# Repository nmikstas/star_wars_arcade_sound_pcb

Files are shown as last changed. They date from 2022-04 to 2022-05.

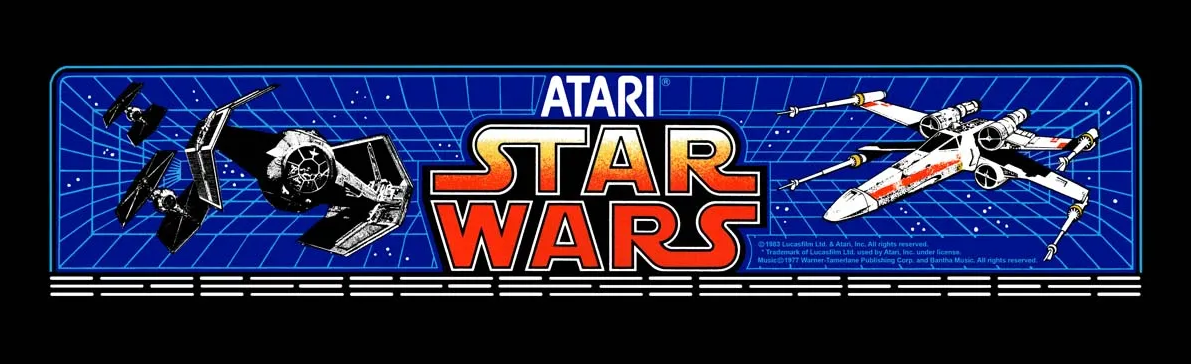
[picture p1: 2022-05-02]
images/star_wars_marquee.png

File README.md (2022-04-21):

# star_wars_arcade_sound_pcb
Reproduction of the Star Wars arcade sound PCB. The PCB is complete but not yet verified.

# Folder Structure
* BOM - Bill of materials for the sound PCB
* Gerbers - The gerber files for the sound PCB
* images - The images used for the sound PCB
* pcb - The Kicad design files for the sound PCB

# PCB Specifications
* Layers: 2
* Dimensions: 293mm X 227mm
* Different PCB Design: 1
* PCB Thickness: 1.6mm
* Surface Finish: HASL
* Castellated Holes: No
* Copper Weight: 1oz.

# The Complete Star Wars Arcade PCB Repository Collection
* Main PCB: https://github.com/nmikstas/star_wars_arcade_main_pcb
* AVG PCB: https://github.com/nmikstas/star_wars_arcade_avg_pcb
* Sound PCB: https://github.com/nmikstas/star_wars_arcade_sound_pcb
* EMI PCB: https://github.com/nmikstas/star_wars_arcade_emi_pcb
* Interconnect PCB: 
* AVG Chip: https://github.com/nmikstas/atari-avg-replacements
* Varistor Replacement: https://github.com/nmikstas/atari_voltage_dependent_resistor
* Mathbox ROM Replacement:
* State Machine Adapter PCB:

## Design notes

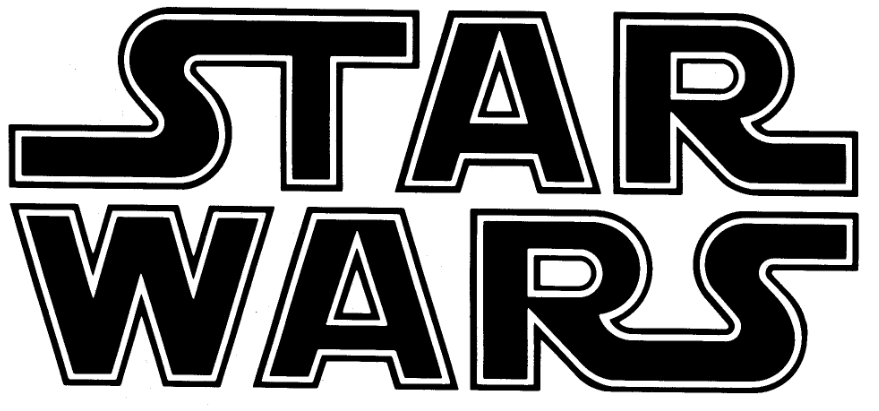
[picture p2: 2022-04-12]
images/star_wars.png

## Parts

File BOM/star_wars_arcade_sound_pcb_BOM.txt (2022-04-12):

Part_ID                                                 QTY     DESC            Part_Num

C1,  C2,  C3,  C4,  C5,  C6,  C7,  C8,  C9,  C10,       41      0.1uf           Digikey 399-4454-1-ND
C11, C12, C16, C17, C18, C19, C20, C22, C23, C24,
C25, C26, C27, C28, C30, C37, C38, C40, C41, C42,
C43, C45, C54, C55, C59, C60, C61, C31, C32, C34,
C36
C46, C48, C49, C50, C56, C57, C58                       7       0.0027uf        Digikey 478-11573-1-ND
C13, C14, C15, C47, C53		                            5       100uf 50V       Digikey 1572-1309-ND
C29, C33, C35, C39                                      4       1000pf          Digikey 1216PHCT-ND
C44                                                     1       0.01uf          Digikey 399-4452-1-ND
C51                                                     1       0.47uf          Digikey 1572-1461-ND‎
C52                                                     1       10uf            Digikey 1572-1294-ND

DS1                                                     1       BLUE LED        Digikey VAOL-5701SBY4-ND

P2                                                      1       7 pin con       Digikey A19878-ND‎

Q1, Q2                                                  2       2N3906          Digikey 2N3906TAFSCT-ND
Q3, Q4                                                  2       2N3904          Digikey 2N3904TAFSCT-ND

R1,  R4,  R7,  R12, R15, R20, R22, R24, R26             9       1K              Digikey 1.0KQBK-ND
R2,  R3,  R5,  R6,  R10, R13, R17, R37                  8       10K             Digikey 10KQBK-ND
R30, R39, R40, R42, R46, R47                            6       12K             Digikey 12KQBK-ND
R21, R23, R50, R54, R55                                 5       47K             Digikey 47KQBK-ND
R48, R49, R52, R53                                      4       22K             Digikey 22KQBK-ND
R35, R51, R56                                           3       2.2K            Digikey 2.2KQBK-ND
R8,  R9,  R44                                           3       100             Digikey 100QBK-ND
R11, R14, R16                                           3       3.3K            Digikey 3.3KQBK-ND
R25, R27                                                2       82K             Digikey 82KQBK-ND
R33, R34                                                2       4.7K            Digikey 4.7KQBK-ND
R31, R32                                                2       560K            Digikey 560KQBK-ND
R19, R28                                                2       100K            Digikey 100KQBK-ND
R18                                                     1       1.8K            Digikey 1.8KQBK-ND
R29                                                     1       15K             Digikey 15KQBK-ND
R36                                                     1       15              Digikey 15QBK-ND
R38                                                     1       470             Digikey 470QBK-ND
R41                                                     1       68K             Digikey 68KQBK-ND
R43                                                     1       1.5K            Digikey 1.5KQBK-ND
R45                                                     1       470K            Digikey 470KQBK-ND

TP1,  TP2, TP3, TP4, TP5, TP6, TP7, TP8, TP9, TP10      12      Test Point      Digikey WM6456-ND
TP11, TP12

D-2, D-3, D-4, D-5                                      4       POKEY           Ebay
B-2, C-3, C-4                                           3       TL084           Digikey 296-1782-5-ND‎
H-1, J/K-1                                              2       2764            Jameco 2303119
F-3, F-5                                                2       LS161           Digikey 296-1646-5-ND
J-2, J-3                                                2       LS139           Digikey 296-1640-5-ND
J-5, K-5                                                2       LS374           Jameco 47634
C/D-1                                                   1       TMS-5220        Ebay
F/H-1                                                   1       6116-2K-RAM     Jameco 242675
F/H-5                                                   1       LS125           Jameco 46501
E-1                                                     1       PIA             Ebay
F-2                                                     1       CD4069/74C04    Jameco 13231
A-3                                                     1       NE556           Jameco 904114
B-3                                                     1       R5106           Ebay
H-2                                                     1       LS04            Jameco 46316
H-3                                                     1       LS00            Jameco 46252
H-5                                                     1       LS74            Jameco 48004
K-3                                                     1       6809E           Ebay

IC Sockets
-------------------
8  pin     1
14 pin     9
16-pin     4
20-pin     2
24-pin     1
28-pin     3
40-pin     6

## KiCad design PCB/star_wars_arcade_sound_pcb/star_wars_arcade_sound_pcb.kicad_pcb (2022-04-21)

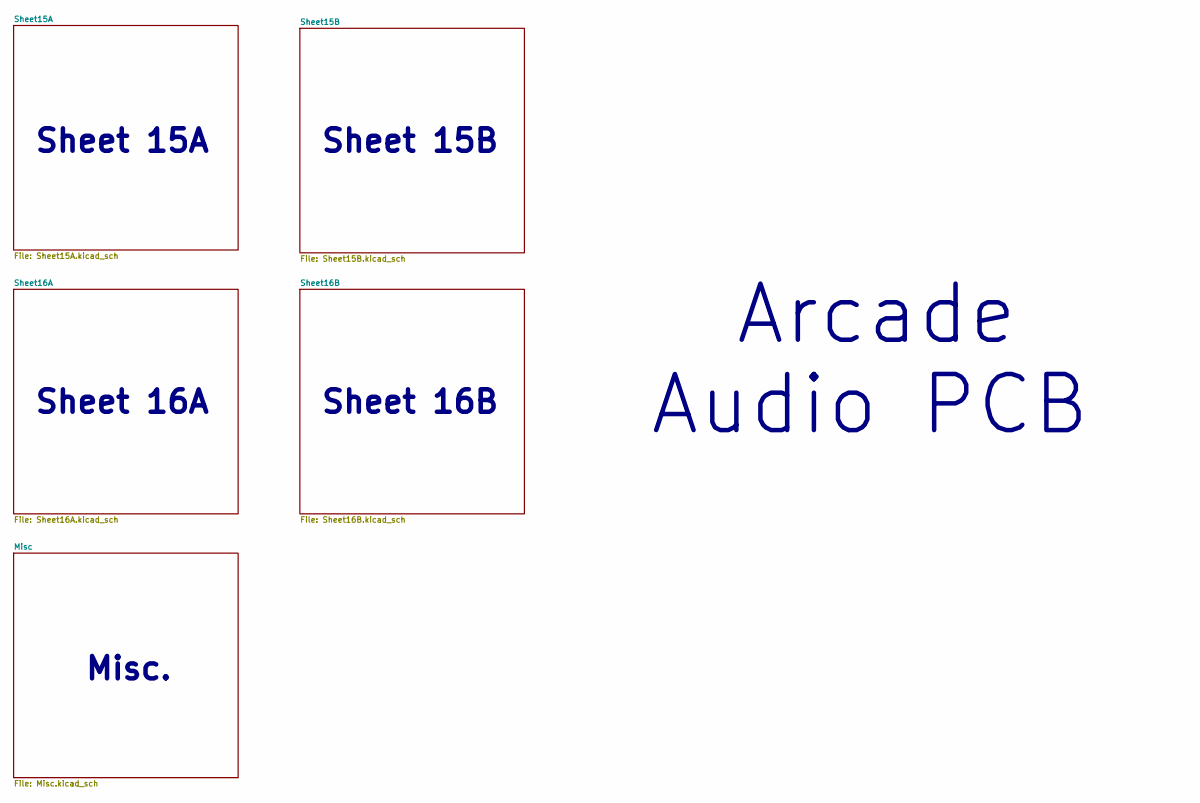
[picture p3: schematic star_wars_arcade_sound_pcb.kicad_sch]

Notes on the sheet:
Sheet 15A
Sheet 16A
Sheet 15B
Arcade Audio PCB
Sheet 16B
Misc.

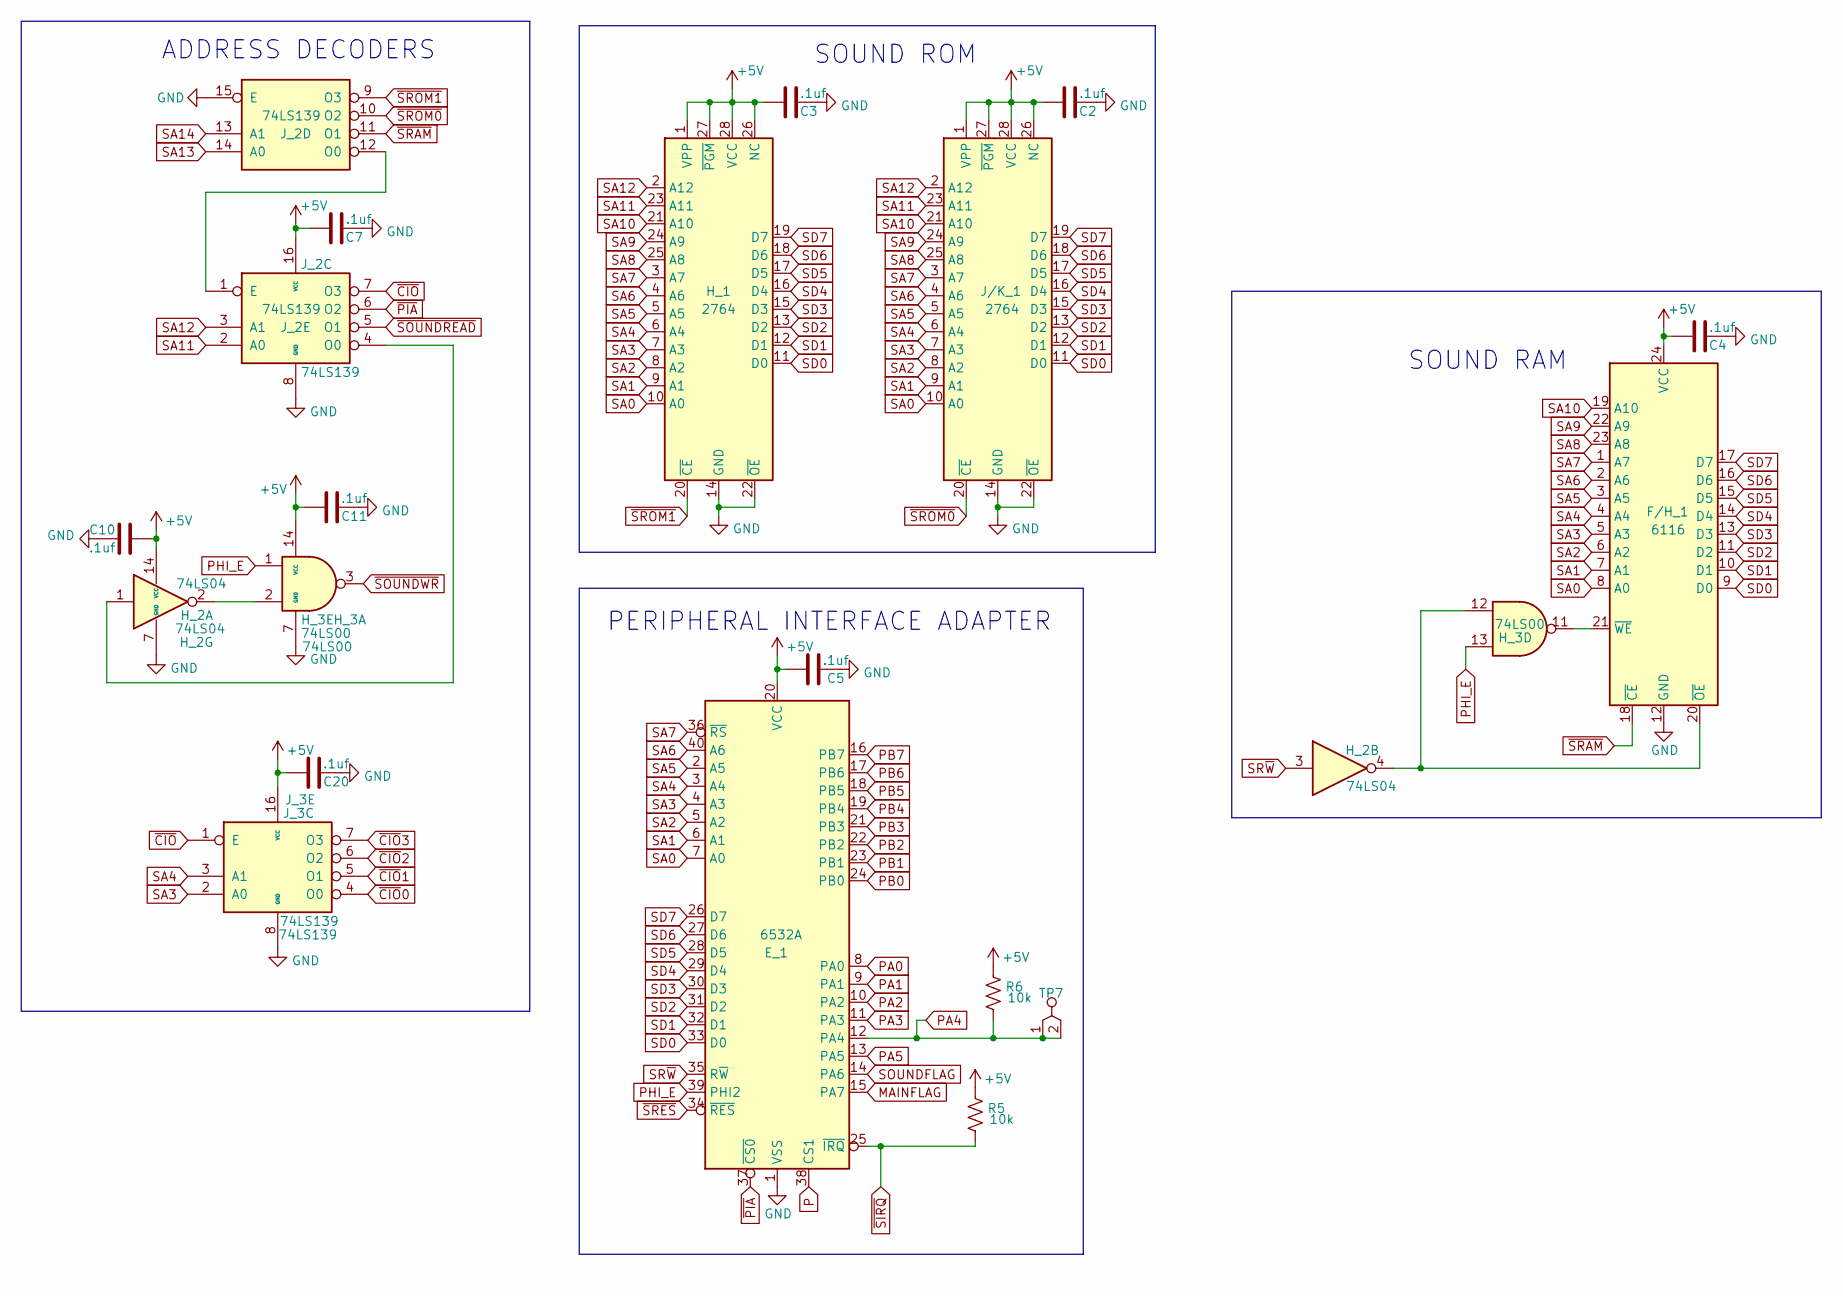
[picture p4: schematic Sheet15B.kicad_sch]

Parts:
C2, C3, C4, C5, C7, C10, C11, C20: .1uf; GenericComp
E_1: 6532A; DDIP40
F/H_1: 6116; DDIP24
H_1: 2764; DIP28
H_2: 74LS04; DIP14
H_3: 74LS00; DIP14
J/K_1: 2764; DIP28
J_2, J_3: 74LS139; DIP16
R5, R6: 10k; GenericComp
TP7: tp_2_pin; TEST_POINT

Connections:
+5V: C2.1, C3.1, C4.1, C5.1, C7.1, C10.1, C11.1, C20.1, E_1.20 (VCC), F/H_1.24 (VCC), H_1.1 (VPP), H_1.26 (NC), H_1.27 (~PGM), H_1.28 (VCC), H_2.14 (VCC), H_3.14 (VCC), J/K_1.1 (VPP), J/K_1.26 (NC), J/K_1.27 (~PGM), J/K_1.28 (VCC), J_2.16 (VCC), J_3.16 (VCC), R5.1, R6.1; also elsewhere on the board
GND: C2.2, C3.2, C4.2, C5.2, C7.2, C10.2, C11.2, C20.2, E_1.1 (VSS), F/H_1.12 (GND), H_1.14 (GND), H_1.22 (~OE), H_2.7 (GND), H_3.7 (GND), J/K_1.14 (GND), J/K_1.22 (~OE), J_2.8 (GND), J_2.15 (E), J_3.8 (GND); also elsewhere on the board
MAINFLAG: E_1.15 (PA7); also elsewhere on the board
unnamed: F/H_1.20 (~OE), H_2.4, H_3.12
unnamed: F/H_1.21 (~WE), H_3.11
unnamed: H_2.1, J_2.4 (O0)
unnamed: H_2.2, H_3.2
unnamed: J_2.1 (E), J_2.12 (O0)
P: E_1.38 (CS1); also elsewhere on the board
PA0: E_1.8 (PA0); also elsewhere on the board
PA1: E_1.9 (PA1); also elsewhere on the board
PA2: E_1.10 (PA2); also elsewhere on the board
PA3: E_1.11 (PA3); also elsewhere on the board
PA4: E_1.12 (PA4), R6.2, TP7.1, TP7.2
PA5: E_1.13 (PA5); also elsewhere on the board
PB0: E_1.24 (PB0); also elsewhere on the board
PB1: E_1.23 (PB1); also elsewhere on the board
PB2: E_1.22 (PB2); also elsewhere on the board
PB3: E_1.21 (PB3); also elsewhere on the board
PB4: E_1.19 (PB4); also elsewhere on the board
PB5: E_1.18 (PB5); also elsewhere on the board
PB6: E_1.17 (PB6); also elsewhere on the board
PB7: E_1.16 (PB7); also elsewhere on the board
PHI_E: E_1.39 (PHI2), H_3.1, H_3.13; also elsewhere on the board
SA0: E_1.7 (A0), F/H_1.8 (A0), H_1.10 (A0), J/K_1.10 (A0); also elsewhere on the board
SA1: E_1.6 (A1), F/H_1.7 (A1), H_1.9 (A1), J/K_1.9 (A1); also elsewhere on the board
SA2: E_1.5 (A2), F/H_1.6 (A2), H_1.8 (A2), J/K_1.8 (A2); also elsewhere on the board
SA3: E_1.4 (A3), F/H_1.5 (A3), H_1.7 (A3), J/K_1.7 (A3), J_3.2 (A0); also elsewhere on the board
SA4: E_1.3 (A4), F/H_1.4 (A4), H_1.6 (A4), J/K_1.6 (A4), J_3.3 (A1); also elsewhere on the board
SA5: E_1.2 (A5), F/H_1.3 (A5), H_1.5 (A5), J/K_1.5 (A5); also elsewhere on the board
SA6: E_1.40 (A6), F/H_1.2 (A6), H_1.4 (A6), J/K_1.4 (A6); also elsewhere on the board
SA7: E_1.36 (~RS), F/H_1.1 (A7), H_1.3 (A7), J/K_1.3 (A7); also elsewhere on the board
SA8: F/H_1.23 (A8), H_1.25 (A8), J/K_1.25 (A8); also elsewhere on the board
SA9: F/H_1.22 (A9), H_1.24 (A9), J/K_1.24 (A9); also elsewhere on the board
SA10: F/H_1.19 (A10), H_1.21 (A10), J/K_1.21 (A10); also elsewhere on the board
SA11: H_1.23 (A11), J/K_1.23 (A11), J_2.2 (A0); also elsewhere on the board
SA12: H_1.2 (A12), J/K_1.2 (A12), J_2.3 (A1); also elsewhere on the board
SA13: J_2.14 (A0); also elsewhere on the board
SA14: J_2.13 (A1); also elsewhere on the board
SD0: E_1.33 (D0), F/H_1.9 (D0), H_1.11 (D0), J/K_1.11 (D0); also elsewhere on the board
SD1: E_1.32 (D1), F/H_1.10 (D1), H_1.12 (D1), J/K_1.12 (D1); also elsewhere on the board
SD2: E_1.31 (D2), F/H_1.11 (D2), H_1.13 (D2), J/K_1.13 (D2); also elsewhere on the board
SD3: E_1.30 (D3), F/H_1.13 (D3), H_1.15 (D3), J/K_1.15 (D3); also elsewhere on the board
SD4: E_1.29 (D4), F/H_1.14 (D4), H_1.16 (D4), J/K_1.16 (D4); also elsewhere on the board
SD5: E_1.28 (D5), F/H_1.15 (D5), H_1.17 (D5), J/K_1.17 (D5); also elsewhere on the board
SD6: E_1.27 (D6), F/H_1.16 (D6), H_1.18 (D6), J/K_1.18 (D6); also elsewhere on the board
SD7: E_1.26 (D7), F/H_1.17 (D7), H_1.19 (D7), J/K_1.19 (D7); also elsewhere on the board
SOUNDFLAG: E_1.14 (PA6); also elsewhere on the board
SR~W: E_1.35 (R~W), H_2.3; also elsewhere on the board
~CIO: J_2.7 (O3), J_3.1 (E)
~CIO0: J_3.4 (O0); also elsewhere on the board
~CIO1: J_3.5 (O1); also elsewhere on the board
~CIO2: J_3.6 (O2); also elsewhere on the board
~CIO3: J_3.7 (O3); also elsewhere on the board
~PIA: E_1.37 (~CS0), J_2.6 (O2)
~SIRQ: E_1.25 (~IRQ), R5.2; also elsewhere on the board
~SOUNDREAD: J_2.5 (O1); also elsewhere on the board
~SOUNDWR: H_3.3; also elsewhere on the board
~SRAM: F/H_1.18 (~CE), J_2.11 (O1)
~SRES: E_1.34 (~RES); also elsewhere on the board
~SROM0: J/K_1.20 (~CE), J_2.10 (O2)
~SROM1: H_1.20 (~CE), J_2.9 (O3)

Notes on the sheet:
PERIPHERAL INTERFACE ADAPTER
ADDRESS DECODERS
SOUND RAM
SOUND ROM

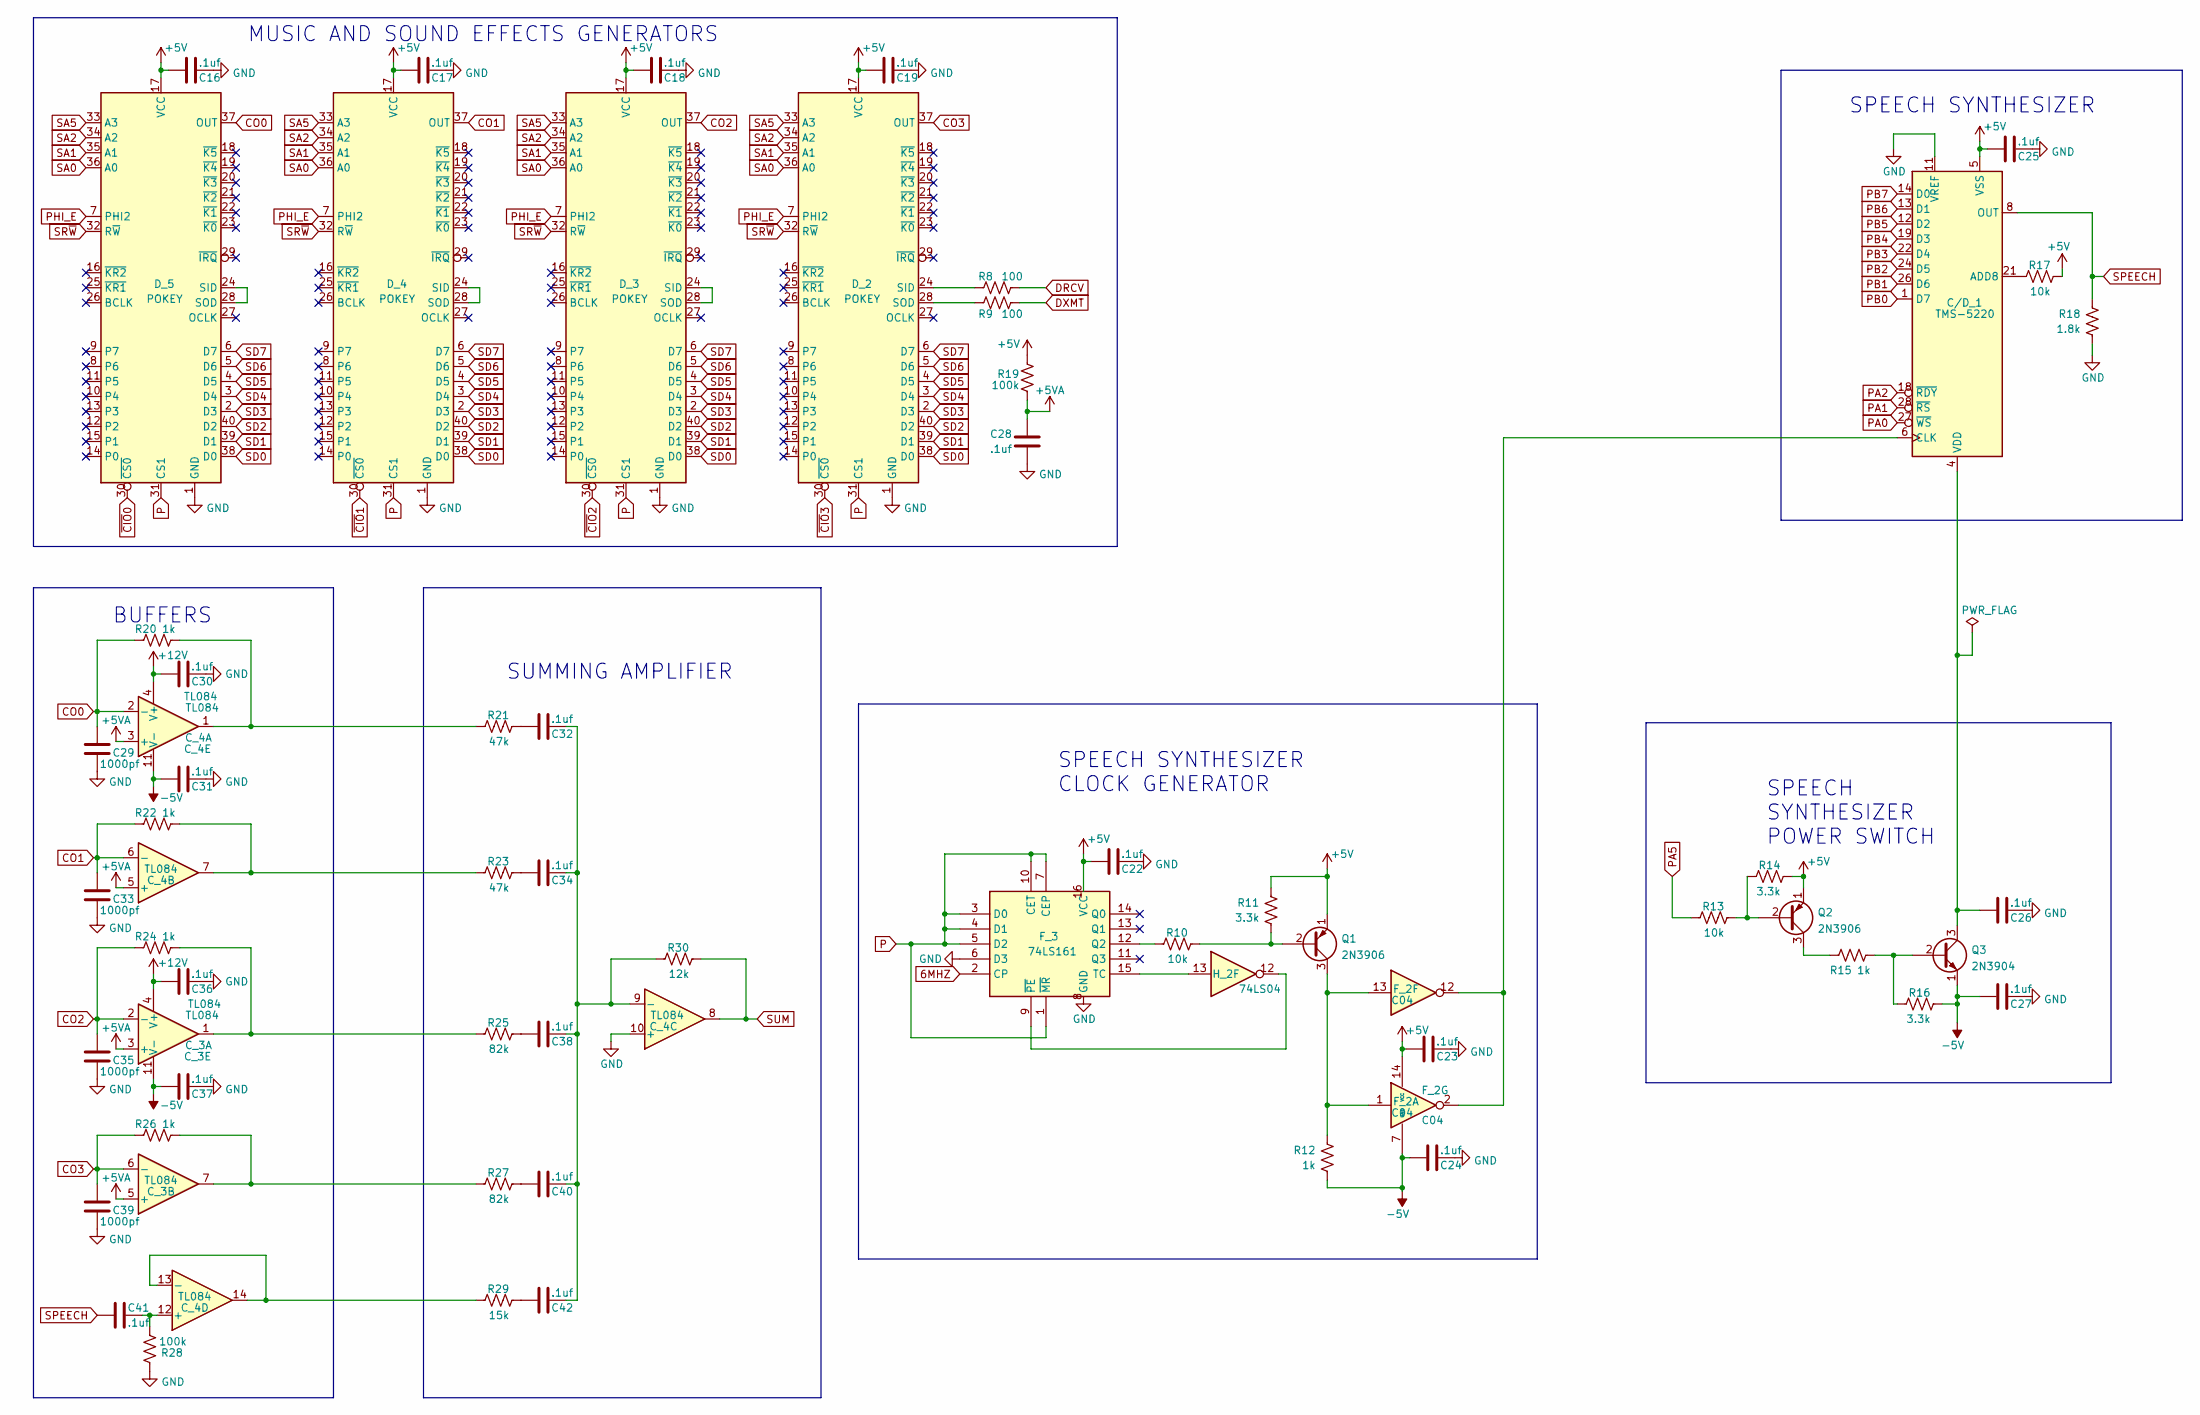
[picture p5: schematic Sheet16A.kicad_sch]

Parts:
C16, C17, C18, C19, C22, C23, C24, C25, C26, C27, C28, C30, C31, C32, C34, C36, C37, C38, C40, C41, C42: .1uf; GenericComp
C29, C33, C35, C39: 1000pf; GenericComp
C/D_1: TMS-5220; DIP28
C_3, C_4: TL084; DIP14
D_2, D_3, D_4, D_5: POKEY; DDIP40
F_2: C04; DIP14
F_3: 74LS161; DIP16
H_2: 74LS04; DIP14
Q1, Q2: 2N3906; GenericTrans
Q3: 2N3904; GenericTrans
R8, R9: 100; GenericComp
R10, R13, R17: 10k; GenericComp
R11, R14, R16: 3.3k; GenericComp
R12, R15, R20, R22, R24, R26: 1k; GenericComp
R18: 1.8k; GenericComp
R19, R28: 100k; GenericComp
R21, R23: 47k; GenericComp
R25, R27: 82k; GenericComp
R29: 15k; GenericComp
R30: 12k; GenericComp

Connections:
6MHZ: F_3.2 (CP); also elsewhere on the board
+5V: C16.1, C17.1, C18.1, C19.1, C22.1, C23.1, C25.1, C/D_1.5 (VSS), D_2.17 (VCC), D_3.17 (VCC), D_4.17 (VCC), D_5.17 (VCC), F_2.14 (VCC), F_3.16 (VCC), Q1.1 (E), Q2.1 (E), R11.2, R14.2, R17.2, R19.2; also elsewhere on the board
+5VA: C28.2, C_3.3 (+), C_3.5 (+), C_4.3 (+), C_4.5 (+), R19.1
+12V: C30.1, C36.1, C_3.4 (V+), C_4.4 (V+); also elsewhere on the board
-5V: C24.1, C27.1, C31.1, C37.1, C_3.11 (V-), C_4.11 (V-), F_2.7 (GND), Q3.1 (E), R12.1, R16.2; also elsewhere on the board
CO0: C29.2, C_4.2 (-), D_5.37 (OUT), R20.1
CO1: C33.2, C_4.6 (-), D_4.37 (OUT), R22.1
CO2: C35.2, C_3.2 (-), D_3.37 (OUT), R24.1
CO3: C39.2, C_3.6 (-), D_2.37 (OUT), R26.1
DRCV: R8.2; also elsewhere on the board
DXMT: R9.2; also elsewhere on the board
GND: C16.2, C17.2, C18.2, C19.2, C22.2, C23.2, C24.2, C25.2, C26.2, C27.2, C28.1, C29.1, C30.2, C31.2, C33.1, C35.1, C36.2, C37.2, C39.1, C/D_1.11 (VREF), C_4.10 (+), D_2.1 (GND), D_3.1 (GND), D_4.1 (GND), D_5.1 (GND), F_3.6 (D3), F_3.8 (GND), R18.1, R28.1; also elsewhere on the board
unnamed: C32.1, R21.2
unnamed: C32.2, C34.2, C38.2, C40.2, C42.2, C_4.9 (-), R30.1
unnamed: C34.1, R23.2
unnamed: C38.1, R25.2
unnamed: C40.1, R27.2
unnamed: C41.1, C_4.12 (+), R28.2
unnamed: C42.1, R29.2
unnamed: C26.1, C/D_1.4 (VDD), Q3.3 (C)
unnamed: C/D_1.6 (CLK), F_2.2, F_2.12
unnamed: C/D_1.21 (ADD8), R17.1
unnamed: C_3.1, R24.2, R25.1
unnamed: C_3.7, R26.2, R27.1
unnamed: C_4.1, R20.2, R21.1
unnamed: C_4.7, R22.2, R23.1
unnamed: C_4.13 (-), C_4.14, R29.1
unnamed: D_2.24 (SID), R8.1
unnamed: D_2.28 (SOD), R9.1
unnamed: D_3.24 (SID), D_3.28 (SOD)
unnamed: D_4.24 (SID), D_4.28 (SOD)
unnamed: D_5.24 (SID), D_5.28 (SOD)
unnamed: F_2.1, F_2.13, Q1.3 (C), R12.2
unnamed: F_3.9 (~PE), H_2.12
unnamed: F_3.12 (Q2), R10.1
unnamed: F_3.15 (TC), H_2.13
unnamed: Q1.2 (B), R10.2, R11.1
unnamed: Q2.2 (B), R13.2, R14.1
unnamed: Q2.3 (C), R15.1
unnamed: Q3.2 (B), R15.2, R16.1
P: D_2.31 (CS1), D_3.31 (CS1), D_4.31 (CS1), D_5.31 (CS1), F_3.1 (~MR), F_3.3 (D0), F_3.4 (D1), F_3.5 (D2), F_3.7 (CEP), F_3.10 (CET); also elsewhere on the board
PA0: C/D_1.27 (~WS); also elsewhere on the board
PA1: C/D_1.28 (~RS); also elsewhere on the board
PA2: C/D_1.18 (~RDY); also elsewhere on the board
PA5: R13.1; also elsewhere on the board
PB0: C/D_1.1 (D7); also elsewhere on the board
PB1: C/D_1.26 (D6); also elsewhere on the board
PB2: C/D_1.24 (D5); also elsewhere on the board
PB3: C/D_1.22 (D4); also elsewhere on the board
PB4: C/D_1.19 (D3); also elsewhere on the board
PB5: C/D_1.12 (D2); also elsewhere on the board
PB6: C/D_1.13 (D1); also elsewhere on the board
PB7: C/D_1.14 (D0); also elsewhere on the board
PHI_E: D_2.7 (PHI2), D_3.7 (PHI2), D_4.7 (PHI2), D_5.7 (PHI2); also elsewhere on the board
SA0: D_2.36 (A0), D_3.36 (A0), D_4.36 (A0), D_5.36 (A0); also elsewhere on the board
SA1: D_2.35 (A1), D_3.35 (A1), D_4.35 (A1), D_5.35 (A1); also elsewhere on the board
SA2: D_2.34 (A2), D_3.34 (A2), D_4.34 (A2), D_5.34 (A2); also elsewhere on the board
SA5: D_2.33 (A3), D_3.33 (A3), D_4.33 (A3), D_5.33 (A3); also elsewhere on the board
SD0: D_2.38 (D0), D_3.38 (D0), D_4.38 (D0), D_5.38 (D0); also elsewhere on the board
SD1: D_2.39 (D1), D_3.39 (D1), D_4.39 (D1), D_5.39 (D1); also elsewhere on the board
SD2: D_2.40 (D2), D_3.40 (D2), D_4.40 (D2), D_5.40 (D2); also elsewhere on the board
SD3: D_2.2 (D3), D_3.2 (D3), D_4.2 (D3), D_5.2 (D3); also elsewhere on the board
SD4: D_2.3 (D4), D_3.3 (D4), D_4.3 (D4), D_5.3 (D4); also elsewhere on the board
SD5: D_2.4 (D5), D_3.4 (D5), D_4.4 (D5), D_5.4 (D5); also elsewhere on the board
SD6: D_2.5 (D6), D_3.5 (D6), D_4.5 (D6), D_5.5 (D6); also elsewhere on the board
SD7: D_2.6 (D7), D_3.6 (D7), D_4.6 (D7), D_5.6 (D7); also elsewhere on the board
SPEECH: C41.2, C/D_1.8 (OUT), R18.2
SR~W: D_2.32 (R~W), D_3.32 (R~W), D_4.32 (R~W), D_5.32 (R~W); also elsewhere on the board
SUM: C_4.8, R30.2; also elsewhere on the board
~CIO0: D_5.30 (~CS0); also elsewhere on the board
~CIO1: D_4.30 (~CS0); also elsewhere on the board
~CIO2: D_3.30 (~CS0); also elsewhere on the board
~CIO3: D_2.30 (~CS0); also elsewhere on the board

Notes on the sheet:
SPEECH SYNTHESIZER CLOCK GENERATOR
BUFFERS
SPEECH SYNTHESIZER POWER SWITCH
MUSIC AND SOUND EFFECTS GENERATORS
SPEECH SYNTHESIZER
SUMMING AMPLIFIER

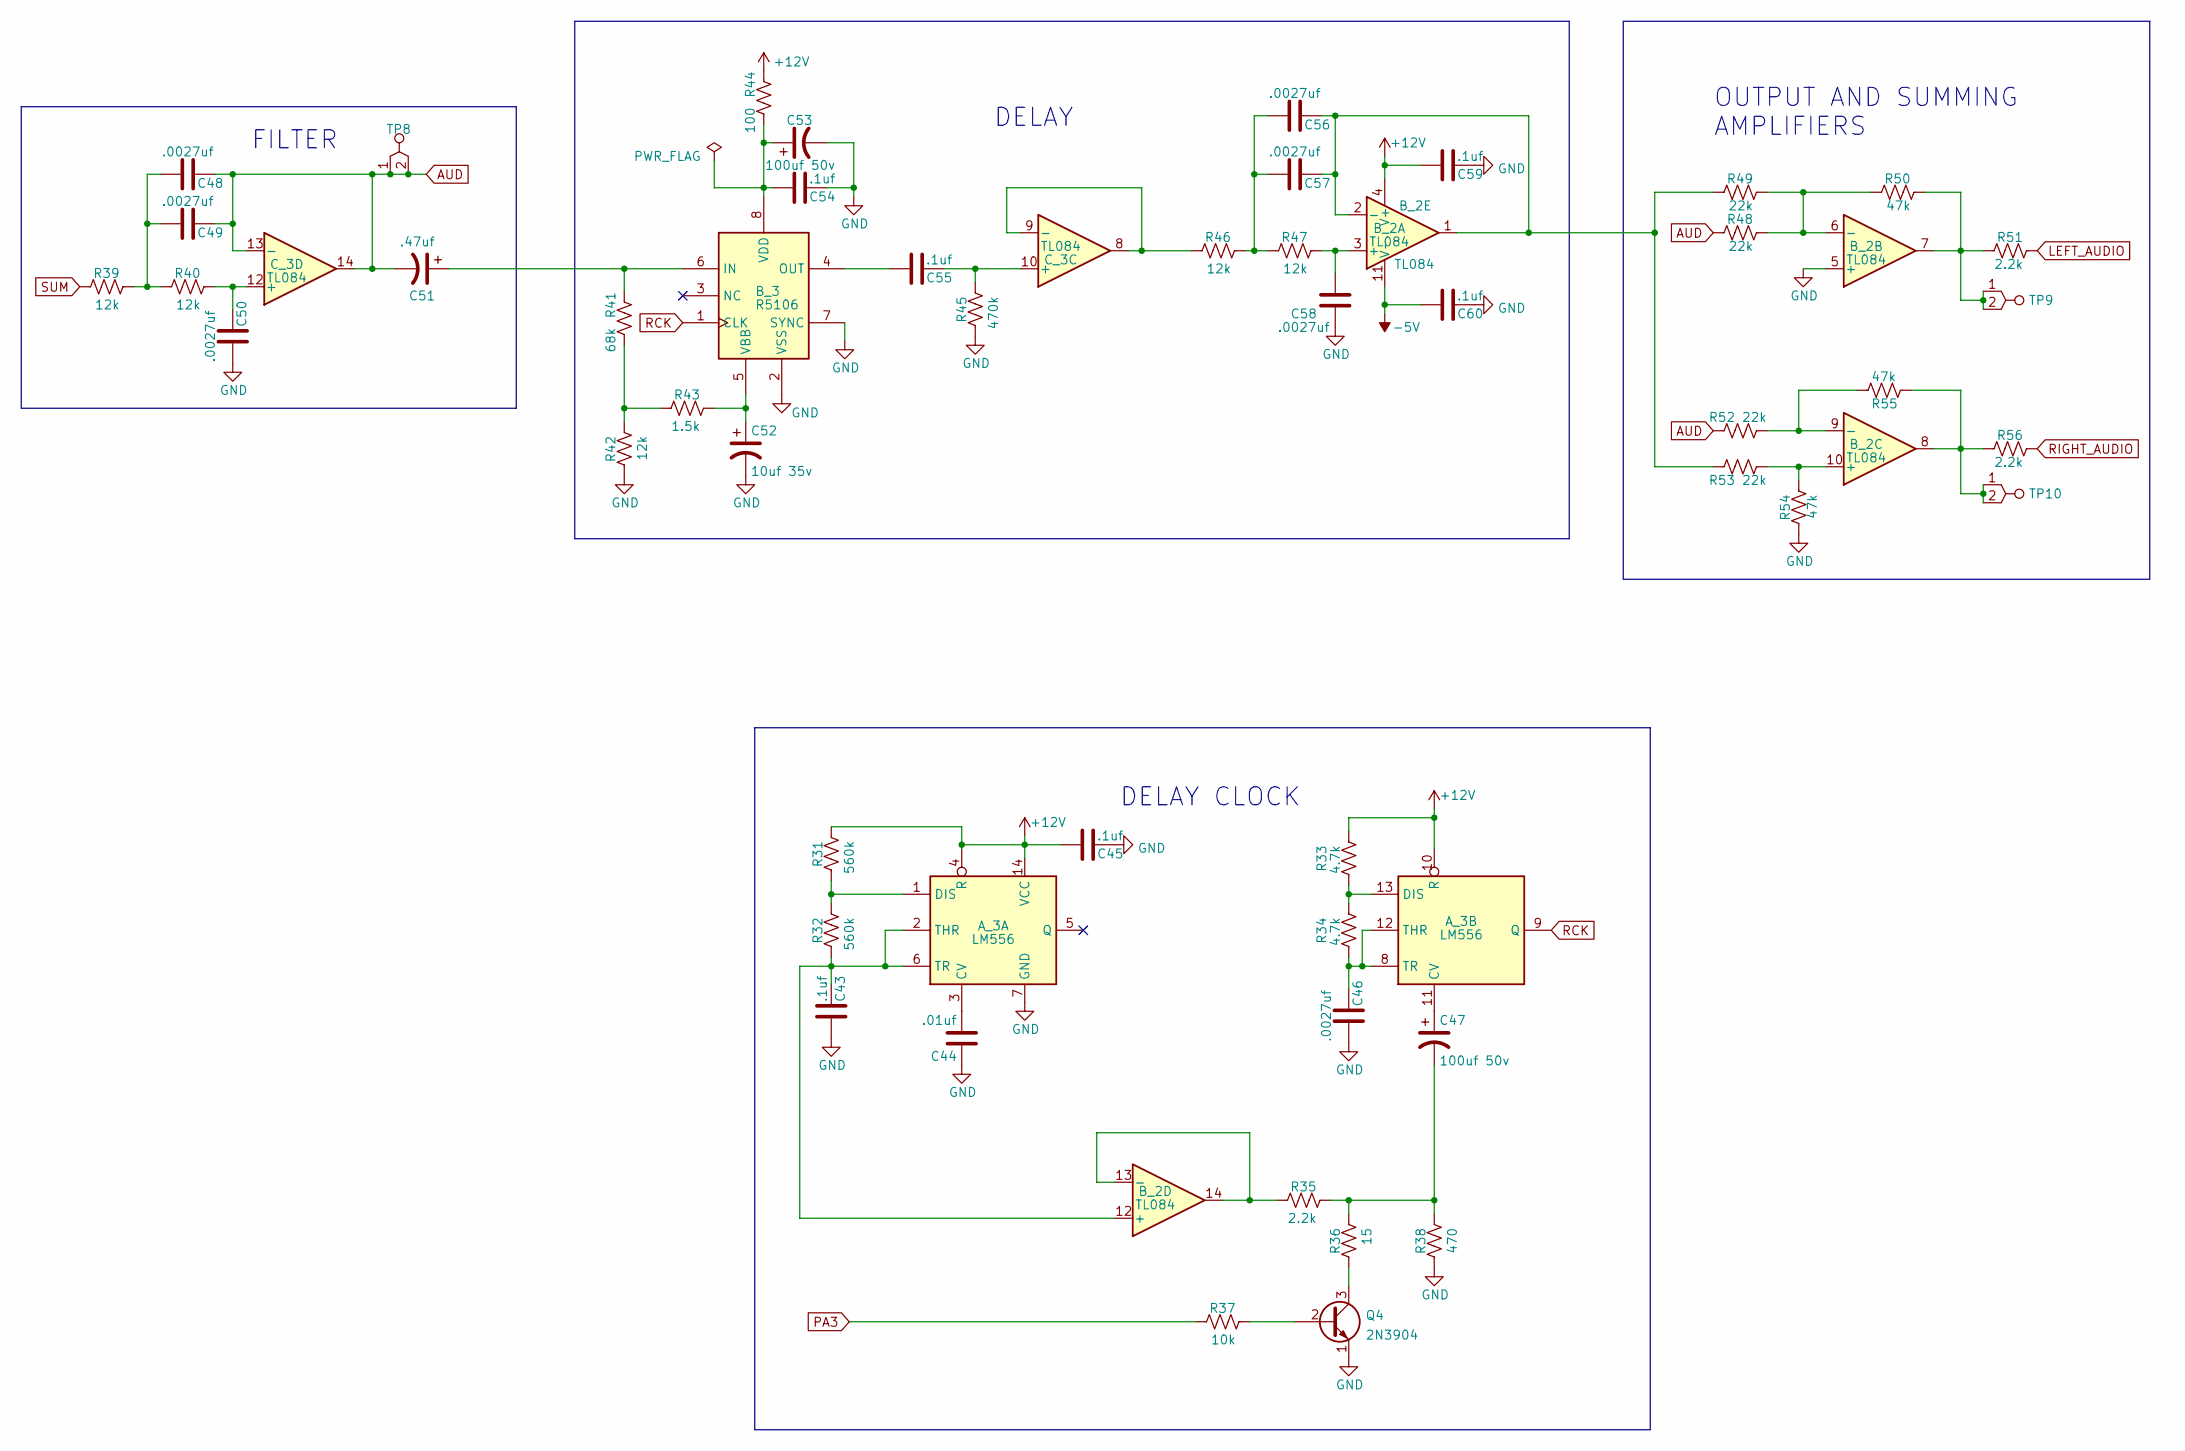
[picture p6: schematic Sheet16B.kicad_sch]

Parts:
A_3: LM556; DIP14
B_2: TL084; DIP14
B_3: R5106; DIP8
C43, C45, C54, C55, C59, C60: .1uf; GenericComp
C44: .01uf; GenericComp
C46, C48, C49, C50, C56, C57, C58: .0027uf; GenericComp
C47, C53: 100uf 50v; LargeCap1
C51: .47uf; MedCap1
C52: 10uf 35v; MedCap1
C_3: TL084; DIP14
Q4: 2N3904; GenericTrans
R31, R32: 560k; GenericComp
R33, R34: 4.7k; GenericComp
R35, R51, R56: 2.2k; GenericComp
R36: 15; GenericComp
R37: 10k; GenericComp
R38: 470; GenericComp
R39, R40, R42, R46, R47: 12k; GenericComp
R41: 68k; GenericComp
R43: 1.5k; GenericComp
R44: 100; GenericComp
R45: 470k; GenericComp
R48, R49, R52, R53: 22k; GenericComp
R50, R54, R55: 47k; GenericComp
TP8, TP9, TP10: tp_2_pin; TEST_POINT

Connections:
+12V: A_3.4 (R), A_3.10 (R), A_3.14 (VCC), B_2.4 (V+), C45.1, C59.1, R31.2, R33.2, R44.2; also elsewhere on the board
-5V: B_2.11 (V-), C60.1; also elsewhere on the board
AUD: C48.2, C49.2, C51.2, C_3.13 (-), C_3.14, R48.1, R52.1, TP8.1, TP8.2
GND: A_3.7 (GND), B_2.5 (+), B_3.2 (VSS), B_3.7 (SYNC), C43.1, C44.1, C45.2, C46.1, C50.1, C52.2, C53.2, C54.2, C58.1, C59.2, C60.2, Q4.1 (E), R38.1, R42.1, R45.1, R54.1; also elsewhere on the board
LEFT_AUDIO: R51.2; also elsewhere on the board
unnamed: A_3.1 (DIS), R31.1, R32.2
unnamed: A_3.2 (THR), A_3.6 (TR), B_2.12 (+), C43.2, R32.1
unnamed: A_3.3 (CV), C44.2
unnamed: A_3.11 (CV), C47.1
unnamed: A_3.8 (TR), A_3.12 (THR), C46.2, R34.1
unnamed: A_3.13 (DIS), R33.1, R34.2
unnamed: B_2.1, B_2.2 (-), C56.2, C57.2, R49.1, R53.1
unnamed: B_2.3 (+), C58.2, R47.2
unnamed: B_2.6 (-), R48.2, R49.2, R50.1
unnamed: B_2.7, R50.2, R51.1, TP9.1, TP9.2
unnamed: B_2.8, R55.1, R56.1, TP10.1, TP10.2
unnamed: B_2.9 (-), R52.2, R55.2
unnamed: B_2.10 (+), R53.2, R54.2
unnamed: B_2.13 (-), B_2.14, R35.1
unnamed: B_3.4 (OUT), C55.1
unnamed: B_3.5 (VBB), C52.1, R43.2
unnamed: B_3.6 (IN), C51.1, R41.2
unnamed: B_3.8 (VDD), C53.1, C54.1, R44.1
unnamed: C47.2, R35.2, R36.2, R38.2
unnamed: C48.1, C49.1, R39.2, R40.1
unnamed: C50.2, C_3.12 (+), R40.2
unnamed: C55.2, C_3.10 (+), R45.2
unnamed: C56.1, C57.1, R46.2, R47.1
unnamed: C_3.8, C_3.9 (-), R46.1
unnamed: Q4.2 (B), R37.2
unnamed: Q4.3 (C), R36.1
unnamed: R41.1, R42.2, R43.1
PA3: R37.1; also elsewhere on the board
RCK: A_3.9 (Q), B_3.1 (CLK)
RIGHT_AUDIO: R56.2; also elsewhere on the board
SUM: R39.1; also elsewhere on the board

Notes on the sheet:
OUTPUT AND SUMMING AMPLIFIERS
DELAY CLOCK
FILTER
DELAY

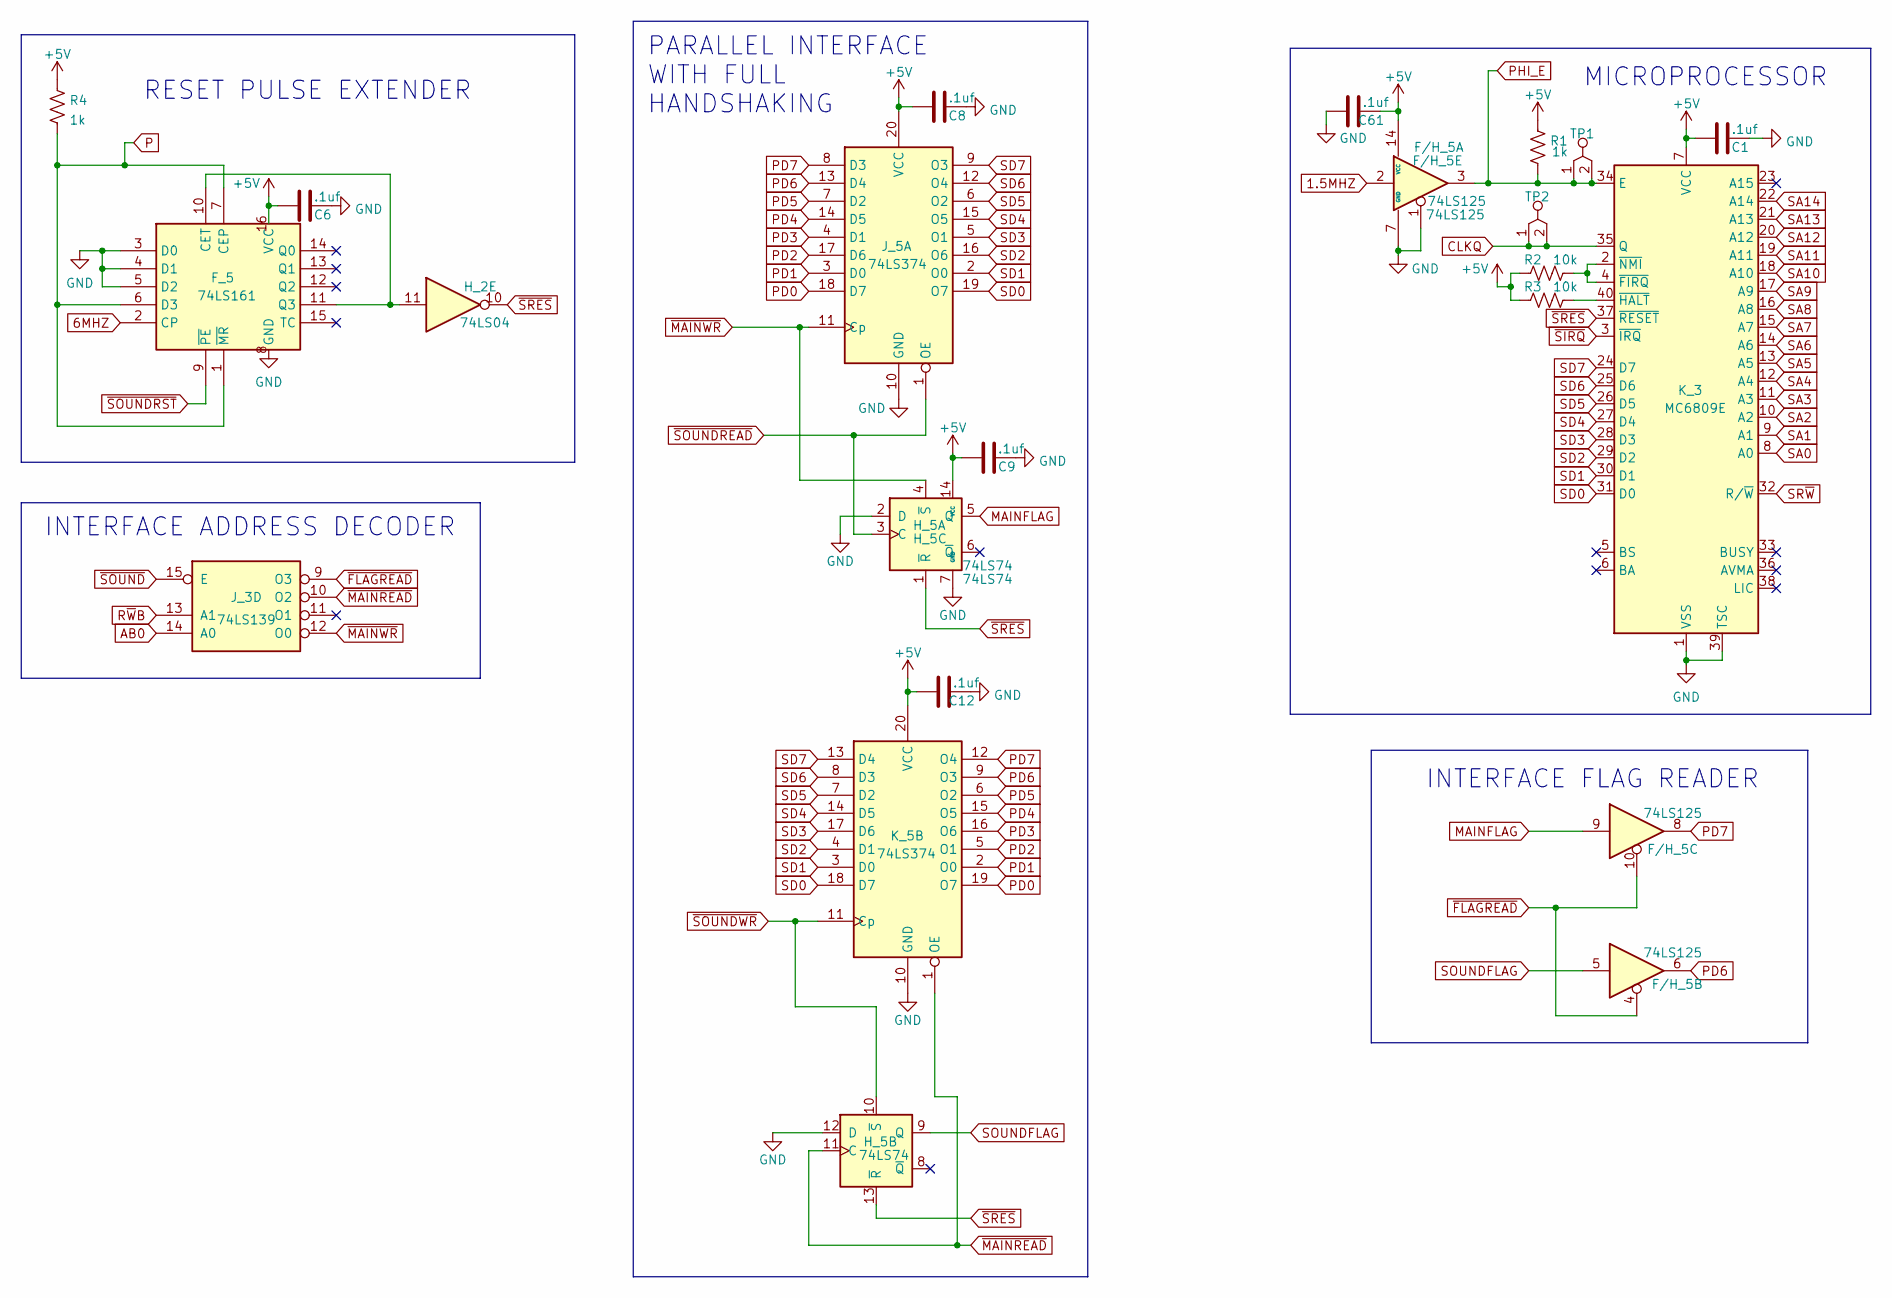
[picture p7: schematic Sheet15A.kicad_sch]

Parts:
C1, C6, C8, C9, C12, C61: .1uf; GenericComp
F/H_5: 74LS125; DIP14
F_5: 74LS161; DIP16
H_2: 74LS04; DIP14
H_5: 74LS74; DIP14
J_3: 74LS139; DIP16
J_5: 74LS374; DIP20
K_3: MC6809E; DDIP40
K_5: 74LS374; DIP20
R1, R4: 1k; GenericComp
R2, R3: 10k; GenericComp
TP1, TP2: tp_2_pin; TEST_POINT

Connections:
1.5MHZ: F/H_5.2; also elsewhere on the board
6MHZ: F_5.2 (CP); also elsewhere on the board
+5V: C1.1, C6.1, C8.1, C9.1, C12.1, C61.2, F/H_5.14 (VCC), F_5.16 (VCC), H_5.14 (VCC), J_5.20 (VCC), K_3.7 (VCC), K_5.20 (VCC), R1.1, R2.1, R3.1, R4.1; also elsewhere on the board
AB0: J_3.14 (A0); also elsewhere on the board
CLKQ: K_3.35 (Q), TP2.1, TP2.2; also elsewhere on the board
GND: C1.2, C6.2, C8.2, C9.2, C12.2, C61.1, F/H_5.1, F/H_5.7 (GND), F_5.3 (D0), F_5.4 (D1), F_5.5 (D2), F_5.8 (GND), H_5.2 (D), H_5.7 (GND), H_5.12 (D), J_5.10 (GND), K_3.1 (VSS), K_3.39 (TSC), K_5.10 (GND); also elsewhere on the board
MAINFLAG: F/H_5.9, H_5.5 (Q); also elsewhere on the board
unnamed: F_5.10 (CET), F_5.11 (Q3), H_2.11
unnamed: K_3.2 (~NMI), K_3.4 (~FIRQ), R2.2
unnamed: K_3.40 (~HALT), R3.2
P: F_5.1 (~MR), F_5.6 (D3), F_5.7 (CEP), R4.2; also elsewhere on the board
PD0: J_5.18 (D7), K_5.19 (O7); also elsewhere on the board
PD1: J_5.3 (D0), K_5.2 (O0); also elsewhere on the board
PD2: J_5.17 (D6), K_5.5 (O1); also elsewhere on the board
PD3: J_5.4 (D1), K_5.16 (O6); also elsewhere on the board
PD4: J_5.14 (D5), K_5.15 (O5); also elsewhere on the board
PD5: J_5.7 (D2), K_5.6 (O2); also elsewhere on the board
PD6: F/H_5.6, J_5.13 (D4), K_5.9 (O3); also elsewhere on the board
PD7: F/H_5.8, J_5.8 (D3), K_5.12 (O4); also elsewhere on the board
PHI_E: F/H_5.3, K_3.34 (E), R1.2, TP1.1, TP1.2; also elsewhere on the board
R~WB: J_3.13 (A1); also elsewhere on the board
SA0: K_3.8 (A0); also elsewhere on the board
SA1: K_3.9 (A1); also elsewhere on the board
SA2: K_3.10 (A2); also elsewhere on the board
SA3: K_3.11 (A3); also elsewhere on the board
SA4: K_3.12 (A4); also elsewhere on the board
SA5: K_3.13 (A5); also elsewhere on the board
SA6: K_3.14 (A6); also elsewhere on the board
SA7: K_3.15 (A7); also elsewhere on the board
SA8: K_3.16 (A8); also elsewhere on the board
SA9: K_3.17 (A9); also elsewhere on the board
SA10: K_3.18 (A10); also elsewhere on the board
SA11: K_3.19 (A11); also elsewhere on the board
SA12: K_3.20 (A12); also elsewhere on the board
SA13: K_3.21 (A13); also elsewhere on the board
SA14: K_3.22 (A14); also elsewhere on the board
SD0: J_5.19 (O7), K_3.31 (D0), K_5.18 (D7); also elsewhere on the board
SD1: J_5.2 (O0), K_3.30 (D1), K_5.3 (D0); also elsewhere on the board
SD2: J_5.16 (O6), K_3.29 (D2), K_5.4 (D1); also elsewhere on the board
SD3: J_5.5 (O1), K_3.28 (D3), K_5.17 (D6); also elsewhere on the board
SD4: J_5.15 (O5), K_3.27 (D4), K_5.14 (D5); also elsewhere on the board
SD5: J_5.6 (O2), K_3.26 (D5), K_5.7 (D2); also elsewhere on the board
SD6: J_5.12 (O4), K_3.25 (D6), K_5.8 (D3); also elsewhere on the board
SD7: J_5.9 (O3), K_3.24 (D7), K_5.13 (D4); also elsewhere on the board
SOUNDFLAG: F/H_5.5, H_5.9 (Q); also elsewhere on the board
SR~W: K_3.32 (R/~W); also elsewhere on the board
~FLAGREAD: F/H_5.4, F/H_5.10, J_3.9 (O3)
~MAINREAD: H_5.11 (C), J_3.10 (O2), K_5.1 (OE)
~MAINWR: H_5.4 (~S), J_3.12 (O0), J_5.11 (Cp)
~SIRQ: K_3.3 (~IRQ); also elsewhere on the board
~SOUNDREAD: H_5.3 (C), J_5.1 (OE); also elsewhere on the board
~SOUNDRST: F_5.9 (~PE); also elsewhere on the board
~SOUNDWR: H_5.10 (~S), K_5.11 (Cp); also elsewhere on the board
~SOUND: J_3.15 (E); also elsewhere on the board
~SRES: H_2.10, H_5.1 (~R), H_5.13 (~R), K_3.37 (~RESET); also elsewhere on the board

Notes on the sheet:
INTERFACE FLAG READER
PARALLEL INTERFACE WITH FULL HANDSHAKING
RESET PULSE EXTENDER
MICROPROCESSOR
INTERFACE ADDRESS DECODER

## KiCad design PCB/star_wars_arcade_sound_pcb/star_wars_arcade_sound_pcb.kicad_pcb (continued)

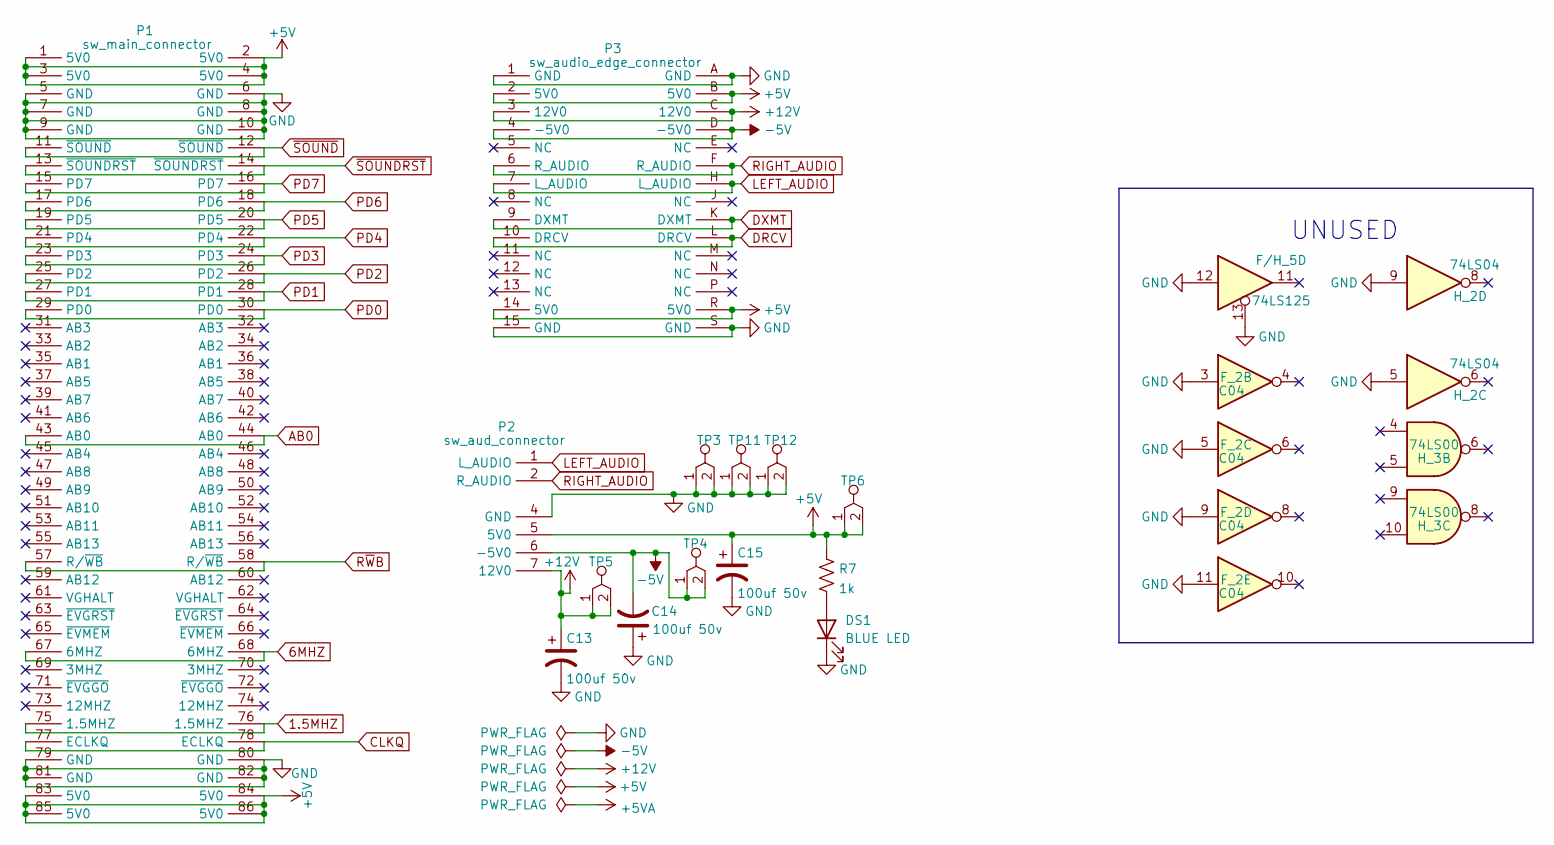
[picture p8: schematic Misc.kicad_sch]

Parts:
C13, C15: 100uf 50v; LargeCap1
C14: 100uf 50v; LargeCap2
DS1: BLUE LED; LED
F/H_5: 74LS125; DIP14
F_2: C04; DIP14
H_2: 74LS04; DIP14
H_3: 74LS00; DIP14
P1: sw_main_connector; P1
P2: sw_aud_connector; Aud_Con
P3: sw_audio_edge_connector; P3
R7: 1k; GenericComp
TP3, TP4, TP5, TP6, TP11, TP12: tp_2_pin; TEST_POINT

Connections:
1.5MHZ: P1.75 (1.5MHZ), P1.76 (1.5MHZ); also elsewhere on the board
6MHZ: P1.67 (6MHZ), P1.68 (6MHZ); also elsewhere on the board
+5V: C15.1, P1.1 (5V0), P1.2 (5V0), P1.3 (5V0), P1.4 (5V0), P1.83 (5V0), P1.84 (5V0), P1.85 (5V0), P1.86 (5V0), P2.5 (5V0), P3.2 (5V0), P3.14 (5V0), P3.B (5V0), P3.R (5V0), R7.1, TP6.1, TP6.2; also elsewhere on the board
+12V: C13.1, P2.7 (12V0), P3.3 (12V0), P3.C (12V0), TP5.1, TP5.2; also elsewhere on the board
-5V: C14.2, P2.6 (-5V0), P3.4 (-5V0), P3.D (-5V0), TP4.1, TP4.2; also elsewhere on the board
AB0: P1.43 (AB0), P1.44 (AB0); also elsewhere on the board
CLKQ: P1.77 (ECLKQ), P1.78 (ECLKQ); also elsewhere on the board
DRCV: P3.10 (DRCV), P3.L (DRCV); also elsewhere on the board
DXMT: P3.9 (DXMT), P3.K (DXMT); also elsewhere on the board
GND: C13.2, C14.1, C15.2, DS1.1 (K), F/H_5.12, F/H_5.13, F_2.3, F_2.5, F_2.9, F_2.11, H_2.5, H_2.9, P1.5 (GND), P1.6 (GND), P1.7 (GND), P1.8 (GND), P1.9 (GND), P1.10 (GND), P1.79 (GND), P1.80 (GND), P1.81 (GND), P1.82 (GND), P2.4 (GND), P3.1 (GND), P3.15 (GND), P3.A (GND), P3.S (GND), TP3.1, TP3.2, TP11.1, TP11.2, TP12.1, TP12.2; also elsewhere on the board
LEFT_AUDIO: P2.1 (L_AUDIO), P3.7 (L_AUDIO), P3.H (L_AUDIO); also elsewhere on the board
unnamed: DS1.2 (A), R7.2
PD0: P1.29 (PD0), P1.30 (PD0); also elsewhere on the board
PD1: P1.27 (PD1), P1.28 (PD1); also elsewhere on the board
PD2: P1.25 (PD2), P1.26 (PD2); also elsewhere on the board
PD3: P1.23 (PD3), P1.24 (PD3); also elsewhere on the board
PD4: P1.21 (PD4), P1.22 (PD4); also elsewhere on the board
PD5: P1.19 (PD5), P1.20 (PD5); also elsewhere on the board
PD6: P1.17 (PD6), P1.18 (PD6); also elsewhere on the board
PD7: P1.15 (PD7), P1.16 (PD7); also elsewhere on the board
RIGHT_AUDIO: P2.2 (R_AUDIO), P3.6 (R_AUDIO), P3.F (R_AUDIO); also elsewhere on the board
R~WB: P1.57 (R/~WB), P1.58 (R/~WB); also elsewhere on the board
~SOUNDRST: P1.13 (~SOUNDRST), P1.14 (~SOUNDRST); also elsewhere on the board
~SOUND: P1.11 (~SOUND), P1.12 (~SOUND); also elsewhere on the board

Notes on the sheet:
UNUSED

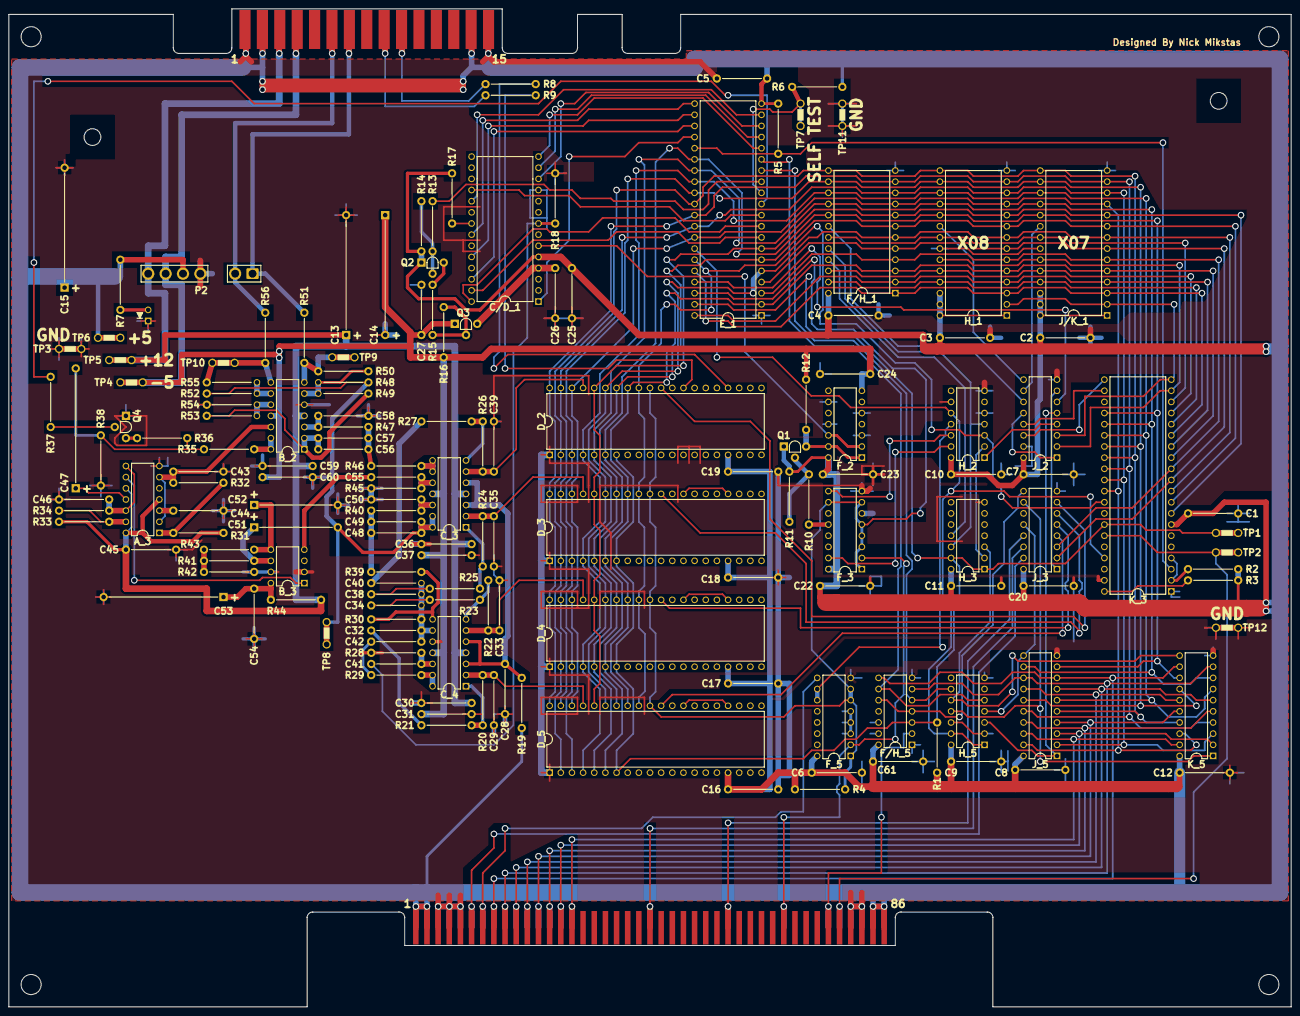
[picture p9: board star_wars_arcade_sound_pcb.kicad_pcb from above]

Board: 2 copper layers, 292.1 x 227.3 mm, 162 parts (0 on the bottom side), 154 nets.

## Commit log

2022-04-12 Worked on schematics
    [Misc.kicad_sch, Sheet15A.kicad_sch, Sheet15B.kicad_sch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]
2022-04-12 Finished schematic
    [Sheet16A.kicad_sch, Sheet16B.kicad_sch, star_wars_arcade_sound_pcb.kicad_sch]
2022-04-12 Began PCB layout
    [Misc.kicad_sch, Sheet15A.kicad_sch, Sheet15B.kicad_sch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]
2022-04-12 ICs placed
    [Sheet15A.kicad_sch, Sheet15B.kicad_sch, Sheet16A.kicad_sch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]
2022-04-13 Placed all components
    [Misc.kicad_sch, Sheet15A.kicad_sch, Sheet15B.kicad_sch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]
2022-04-13 Silkscreen work
    [star_wars_arcade_sound_pcb.kicad_pcb]
2022-04-13 Trace work
    [star_wars_arcade_sound_pcb.kicad_pcb]
2022-04-14 374 connections remain
    [Sheet15B.kicad_sch, star_wars_arcade_sound_pcb.kicad_pcb]
2022-04-15 331 connections remain
    [Sheet16A.kicad_sch, star_wars_arcade_sound_pcb.kicad_pcb, star_wars_arcade_sound_pcb.kicad_sch]
2022-04-15 285 connections remain
    [star_wars_arcade_sound_pcb.kicad_pcb]
2022-04-16 189 connections remain
    [star_wars_arcade_sound_pcb.kicad_pcb]
2022-04-16 Ground plane and mounting holes remain
    [Sheet16B.kicad_sch, star_wars_arcade_sound_pcb.kicad_pcb, star_wars_arcade_sound_pcb.kicad_sch]
2022-04-17 Bottom ground plane and mounting holes remain
2022-04-18 Bottom keep out areas remain
    [Misc.kicad_sch, Sheet16B.kicad_sch]
2022-04-20 Consolidated keep out areas
    [star_wars_arcade_sound_pcb.kicad_pcb]
2022-04-21 Completed PCB
    [star_wars_arcade_sound_pcb.kicad_pcb]
2022-04-21 Added gerbers
    [star_wars_arcade_sound_pcb-B_Cu.gbr, star_wars_arcade_sound_pcb-B_Mask.gbr, star_wars_arcade_sound_pcb-B_Silkscreen.gbr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]
2022-05-02 Updated schematic
